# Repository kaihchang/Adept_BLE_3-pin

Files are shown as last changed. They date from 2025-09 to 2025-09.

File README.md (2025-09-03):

# Adept_BLE_3-pin

Took open source [Adept BLE design](https://github.com/taichan1113/AdeptBLE) and altered PCB &amp; casing for 3-pin micro switches.

Note that the casing is designed for **1.2mm thick PCBs.** Very important.

My version of ZMK firmware is [here.](https://github.com/kaihchang/zmk-config-adept)

Altered PCB:


Altered cases:
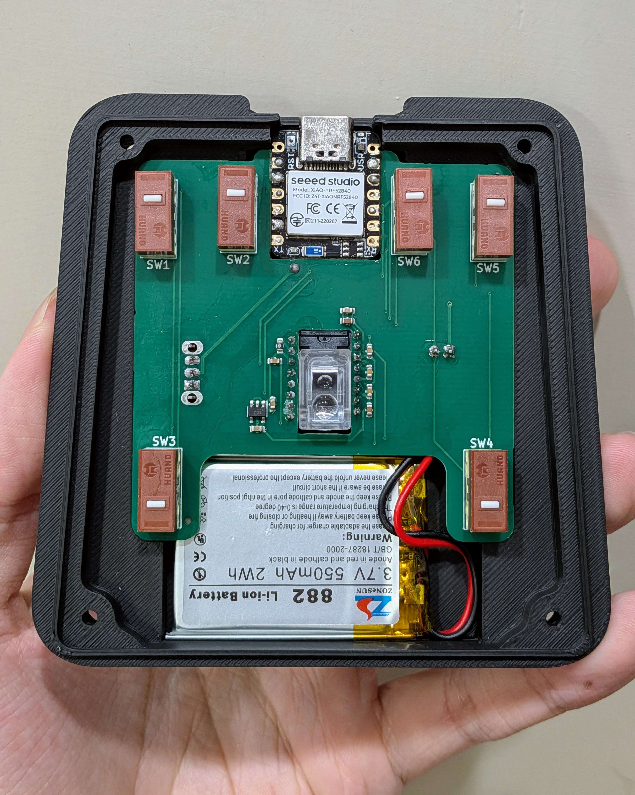
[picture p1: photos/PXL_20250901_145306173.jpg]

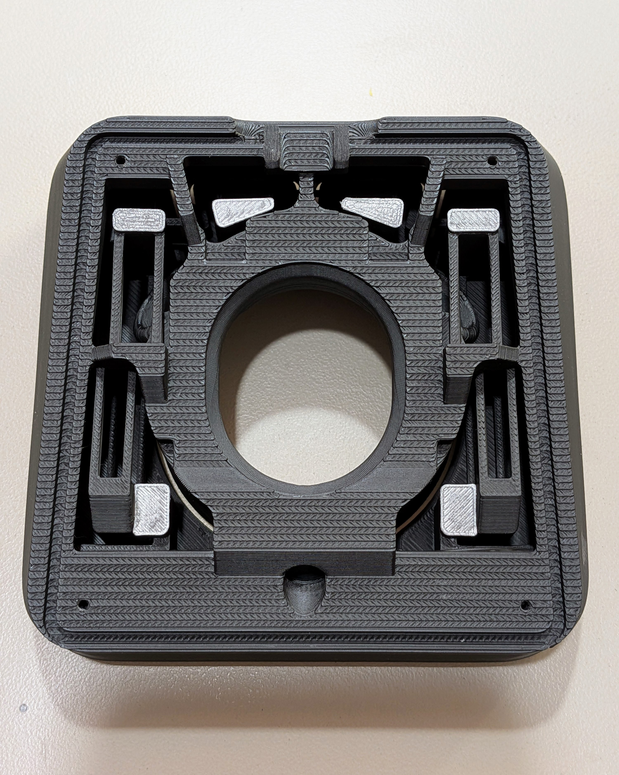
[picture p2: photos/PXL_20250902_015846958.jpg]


Finished build:
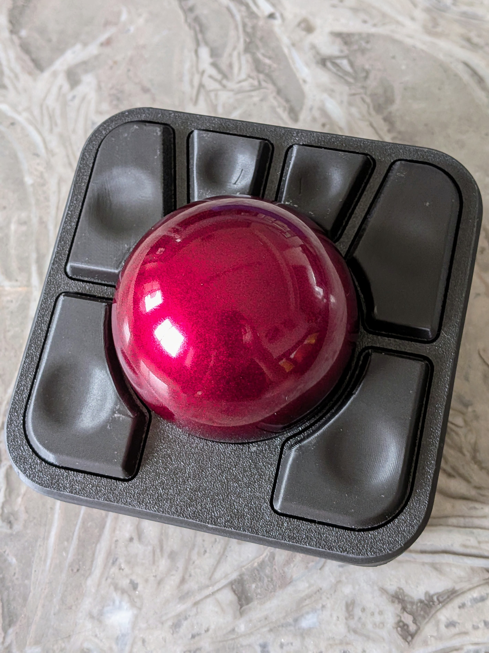
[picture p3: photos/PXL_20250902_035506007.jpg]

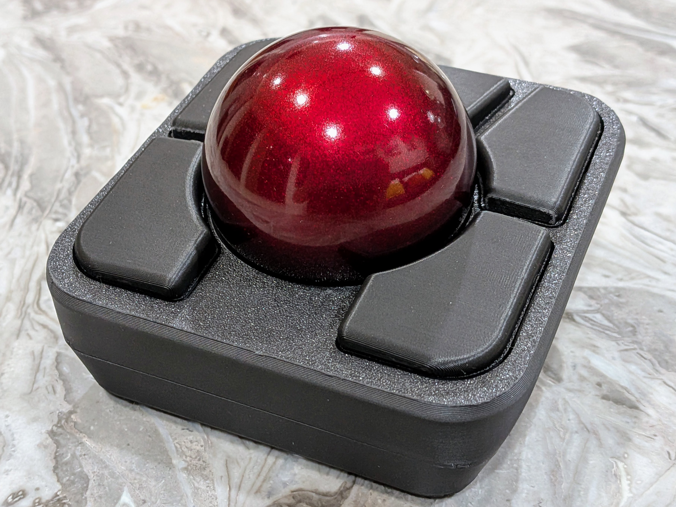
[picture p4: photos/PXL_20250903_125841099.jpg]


Supports BTU and magnet caps. BTW I used CY-8H BTUs and wasn't really satisfied with the quality, even after lubing with grease. SP-8 ones may be a better bet if *Rexroth R053XX8XX (7210)* isn't available or out of price range.
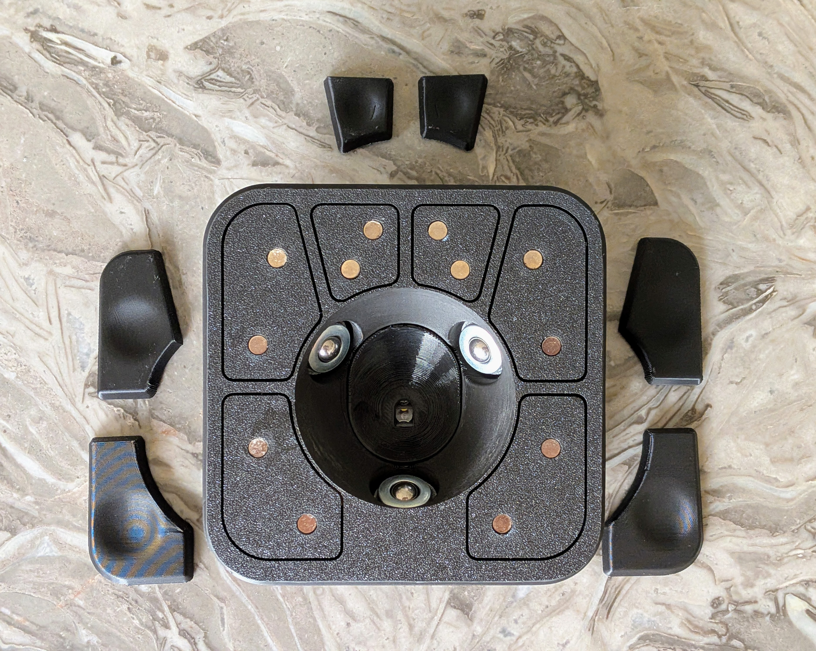
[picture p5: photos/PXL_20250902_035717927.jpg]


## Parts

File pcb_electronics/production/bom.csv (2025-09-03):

Designator | Footprint | Quantity | Value | LCSC Part #
C1 | 0603 | 1 | 10n | C19666
C2, C7 | 0603 | 2 | 100n | C19666
C3 | 0603 | 1 | 3.3u/16V | C19666
C4 | 0603 | 1 | 0.1u | C14663
C5 | 0603 | 1 | 1u | C15849
C6 | 0603 | 1 | 100n (X7R) | C19666
C8 | 0603 | 1 | 10u (X7R) | C19666
C9 | 0603 | 1 | 10n (X7R) | C19666
J1 | JST_XH_S2B-XH-A-1_1x02_P2.50mm_Horizontal | 1 | Conn_01x02
J2, J3 | PinHeader_1x06_P2.54mm_Vertical | 2 | Conn_01x06
J4 | PinHeader_1x01_P2.54mm_Vertical | 1 | Conn_01x01
PSW1 | SW_Slide_SPDT_Straight_CK_OS102011MS2Q | 1 | SW_SPDT
R1 | 0603 | 1 | 2M
SW1, SW2, SW3, SW4, SW5, SW6 | SW_D2FC-1F_3_OMR_edit | 6 | D2LS-21
U1 | SOT-23-5 | 1 | TCR2EF19 | C146366
U2 | PMW3610 | 1 | PMW3610

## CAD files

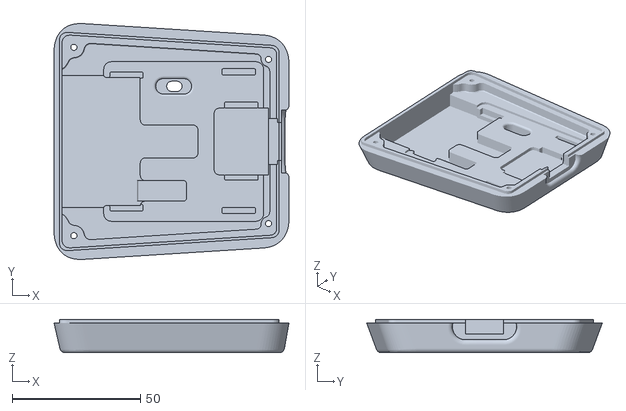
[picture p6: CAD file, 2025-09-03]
3d_print_casings/bottom_casing_xh254.stl
91.6 x 91.9 x 13.0

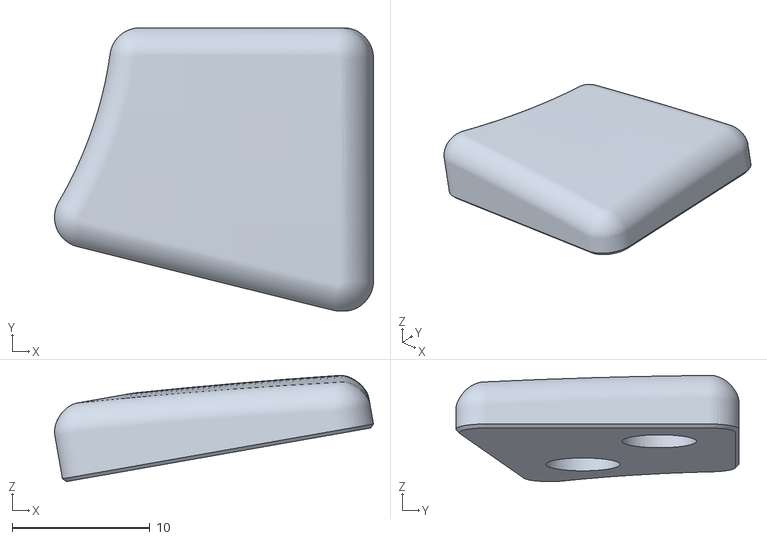
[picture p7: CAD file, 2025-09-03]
3d_print_casings/magnet_buttons/flat/button_flat_5x1.2mm_3.stl
23.1 x 20.6 x 7.71

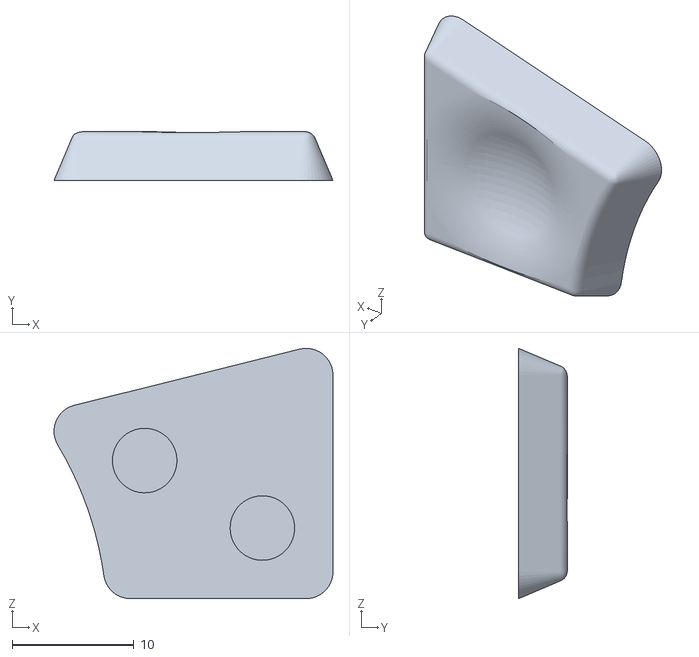
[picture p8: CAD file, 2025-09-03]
3d_print_casings/magnet_buttons/spherical/button_spherical_5x1.5mm_3.stl
22.9 x 4.00 x 20.6

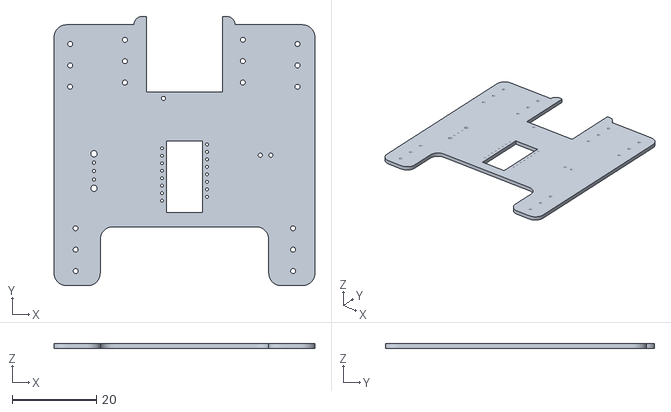
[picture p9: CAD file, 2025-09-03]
pcb_electronics/adept_3pin_pcb_edit.stl
62.0 x 64.0 x 1.20

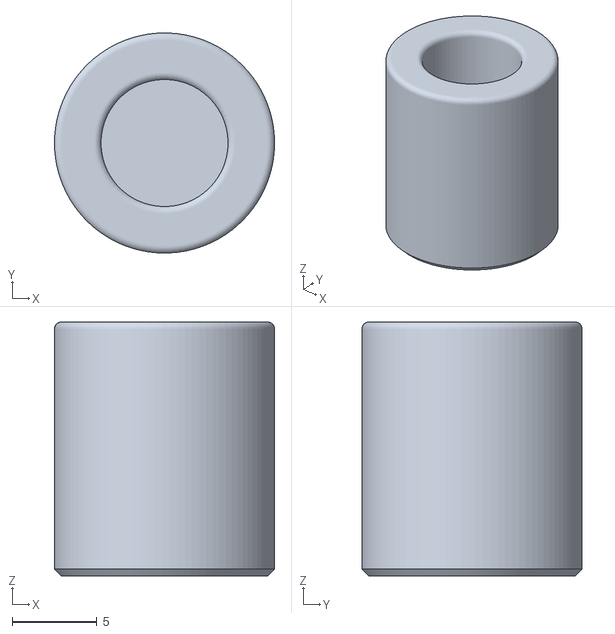
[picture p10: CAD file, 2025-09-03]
3d_print_casings/BTU_pusher.stl
13.0 x 13.0 x 15.0

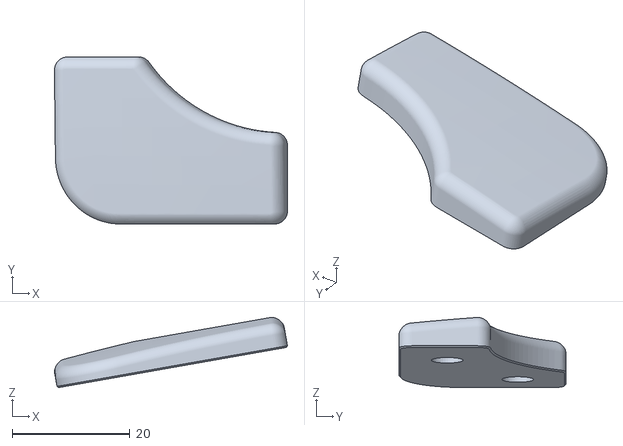
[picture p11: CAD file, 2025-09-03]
3d_print_casings/magnet_buttons/flat/button_flat_5x1.2mm_6.stl
39.6 x 28.4 x 11.9

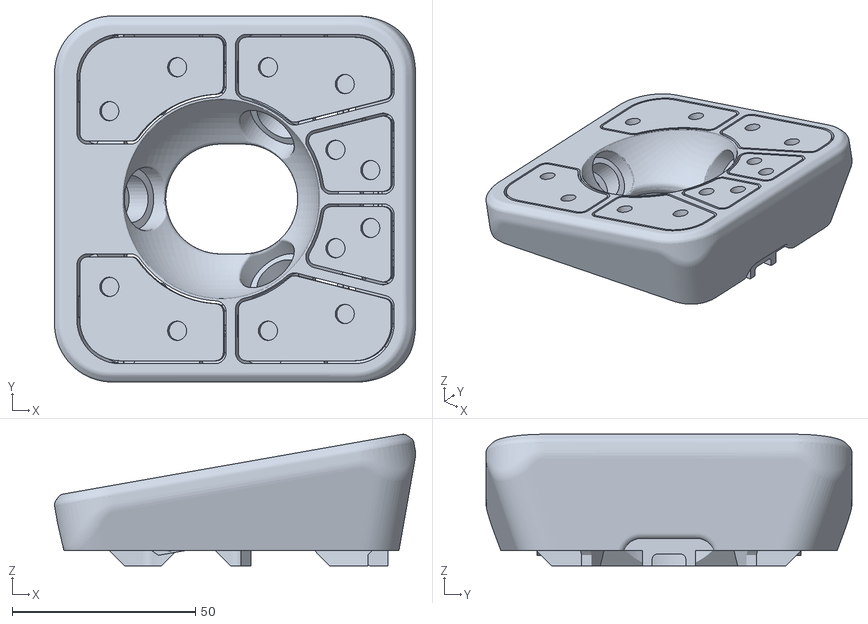
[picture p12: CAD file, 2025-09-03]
pcb_electronics/adept_55mm_top_casing_edit.stl
98.7 x 100.0 x 36.0

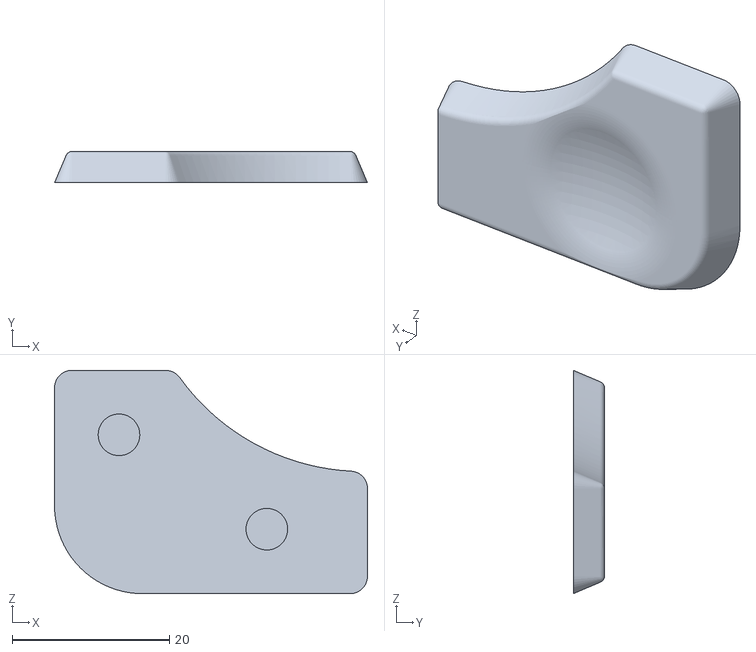
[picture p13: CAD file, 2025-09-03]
3d_print_casings/magnet_buttons/spherical/button_spherical_5x1.5mm_6.stl
39.8 x 4.00 x 28.4

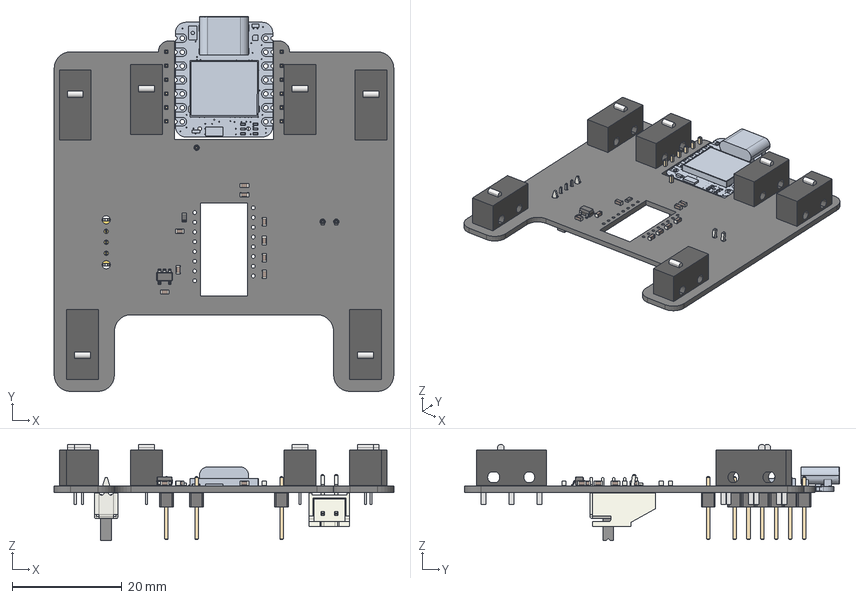
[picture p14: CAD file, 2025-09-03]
pcb_electronics/sensor.step
62.0 x 68.5 x 17.6 mm
SOT-23-5
C_0603_1608Metric x 9
sensor 1.8.1
D2F_01F_BASE x 6
D2F_01F_ACTUATOR x 6
R_0603_1608Metric
PinHeader_1x06_P2.54mm_Vertical x 2
SW_Slide_SPDT_Straight_CK_OS102011MS2Q
PinHeader_1x01_P2.54mm_Vertical
JST_XH_S2B-XH-A-1_1x02_P2.50mm_Horizontal
sensor_PCB

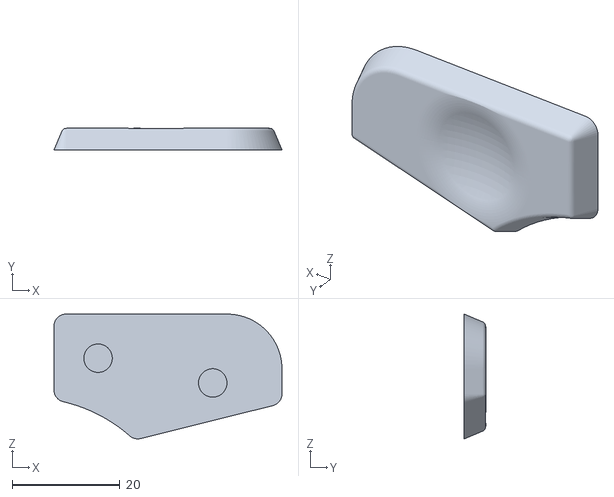
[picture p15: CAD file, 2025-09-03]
3d_print_casings/magnet_buttons/spherical/button_spherical_5x1.5mm_2.stl
42.4 x 4.00 x 23.2

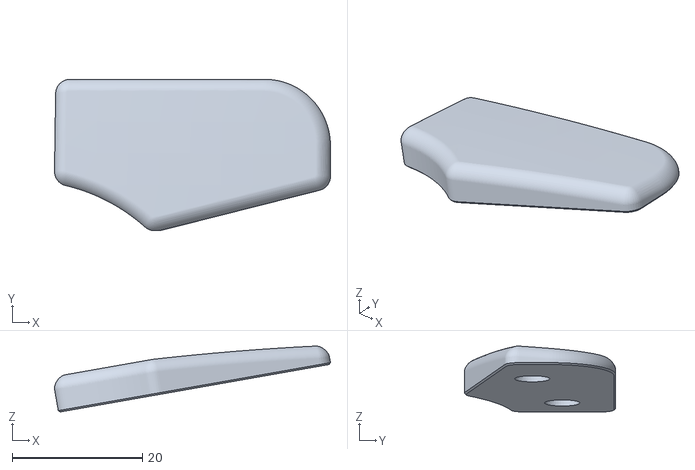
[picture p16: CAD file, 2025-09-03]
3d_print_casings/magnet_buttons/flat/button_flat_5x1.2mm_1.stl
42.3 x 23.2 x 10.1

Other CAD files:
3d_print_casings/magnet_buttons/spherical/button_spherical_5x1.5mm_4.stl
3d_print_casings/magnet_buttons/flat/button_flat_5x1.2mm_2.stl
3d_print_casings/top_casing_55mm.stl
3d_print_casings/magnet_buttons/flat/button_flat_5x1.2mm_5.stl
3d_print_casings/magnet_buttons/spherical/button_spherical_5x1.5mm_1.stl
3d_print_casings/magnet_buttons/flat/button_flat_5x1.2mm_4.stl

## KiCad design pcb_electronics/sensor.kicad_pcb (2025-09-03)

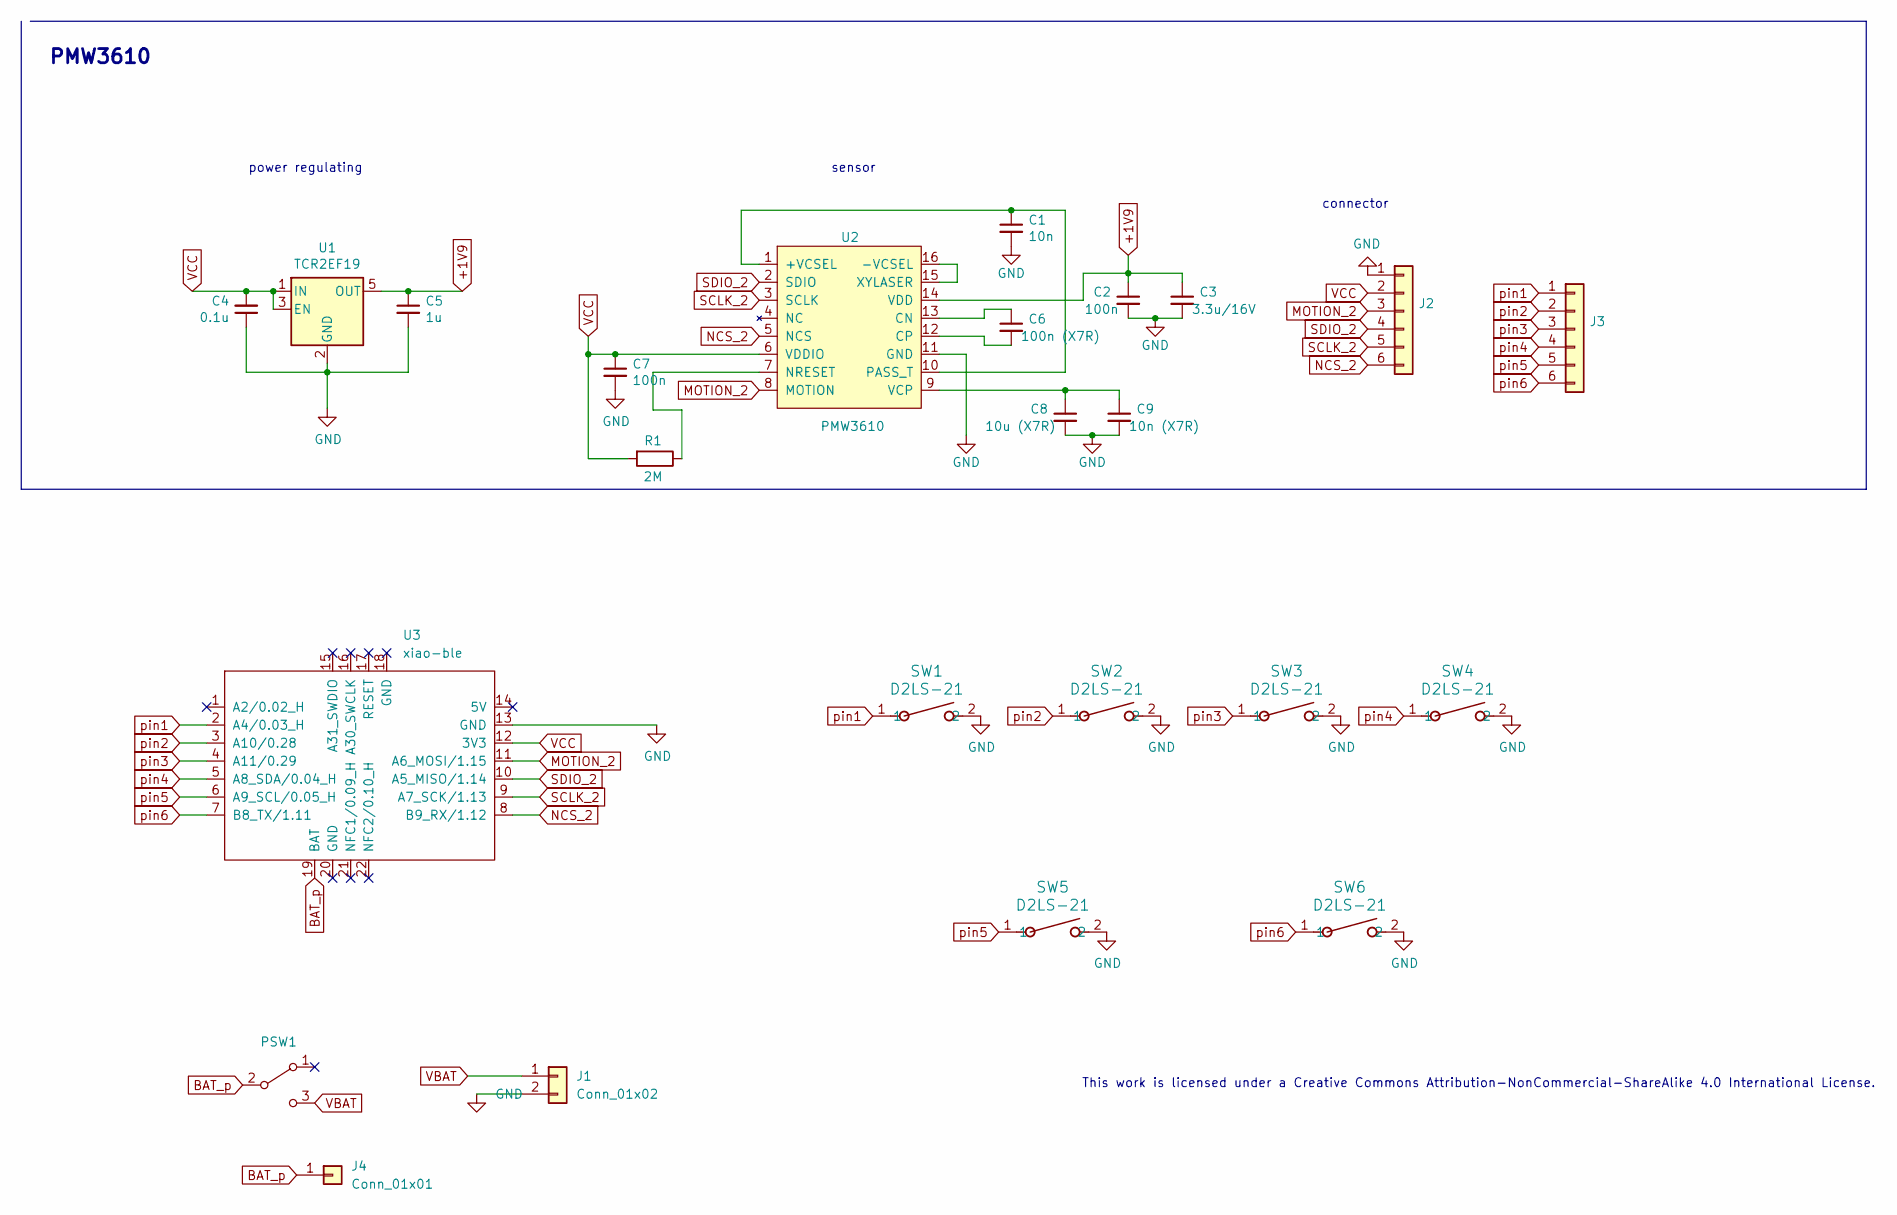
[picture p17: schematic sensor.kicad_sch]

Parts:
C1: 10n; C_0603_1608Metric; LCSC C19666
C2, C7: 100n; C_0603_1608Metric; LCSC C19666
C3: 3.3u/16V; C_0603_1608Metric; LCSC C19666
C4: 0.1u; C_0603_1608Metric; LCSC C14663
C5: 1u; C_0603_1608Metric; LCSC C15849
C6: 100n (X7R); C_0603_1608Metric; LCSC C19666
C8: 10u (X7R); C_0603_1608Metric; LCSC C19666
C9: 10n (X7R); C_0603_1608Metric; LCSC C19666
J1: Conn_01x02; JST_XH_S2B-XH-A-1_1x02_P2.50mm_Horizontal
J2, J3: Conn_01x06; PinHeader_1x06_P2.54mm_Vertical
J4: Conn_01x01; PinHeader_1x01_P2.54mm_Vertical
PSW1: SW_SPDT; SW_Slide_SPDT_Straight_CK_OS102011MS2Q
R1: 2M; R_0603_1608Metric
SW1, SW2, SW3, SW4, SW5, SW6: D2LS-21; SW_D2FC-1F_3_OMR_edit
U1: TCR2EF19; SOT-23-5; LCSC C146366
U2: PMW3610
U3: xiao-ble; xiao-ble-tht

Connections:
+1V9: C2.1, C3.1, C5.1, U1.5 (OUT), U2.14 (VDD)
BAT_p: J4.1, PSW1.2 (B), U3.19 (BAT)
GND: C1.2, C2.2, C3.2, C4.1, C5.2, C7.2, C8.2, C9.2, J1.2, J2.1, SW1.2, SW2.2, SW3.2, SW4.2, SW5.2, SW6.2, U1.2 (GND), U2.11 (GND), U3.13 (GND)
MOTION_2: J2.3, U2.8 (MOTION), U3.11 (A6_MOSI/1.15)
NCS_2: J2.6, U2.5 (NCS), U3.8 (B9_RX/1.12)
unnamed: C1.1, U2.1 (+VCSEL), U2.10 (PASS_T)
unnamed: U2.15 (XYLASER), U2.16 (-VCSEL)
unnamed: C6.1, U2.13 (CN)
unnamed: C6.2, U2.12 (CP)
unnamed: R1.1, U2.7 (NRESET)
unnamed: C8.1, C9.1, U2.9 (VCP)
SCLK_2: J2.5, U2.3 (SCLK), U3.9 (A7_SCK/1.13)
SDIO_2: J2.4, U2.2 (SDIO), U3.10 (A5_MISO/1.14)
VBAT: J1.1, PSW1.3 (C)
VCC: C4.2, C7.1, J2.2, R1.2, U1.1 (IN), U1.3 (EN), U2.6 (VDDIO), U3.12 (3V3)
pin1: J3.1, SW1.1, U3.2 (A4/0.03_H)
pin2: J3.2, SW2.1, U3.3 (A10/0.28)
pin3: J3.3, SW3.1, U3.4 (A11/0.29)
pin4: J3.4, SW4.1, U3.5 (A8_SDA/0.04_H)
pin5: J3.5, SW5.1, U3.6 (A9_SCL/0.05_H)
pin6: J3.6, SW6.1, U3.7 (B8_TX/1.11)

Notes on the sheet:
This work is licensed under a Creative Commons Attribution-NonCommercial-ShareAlike 4.0 International License.
sensor
PMW3610
power regulating
connector

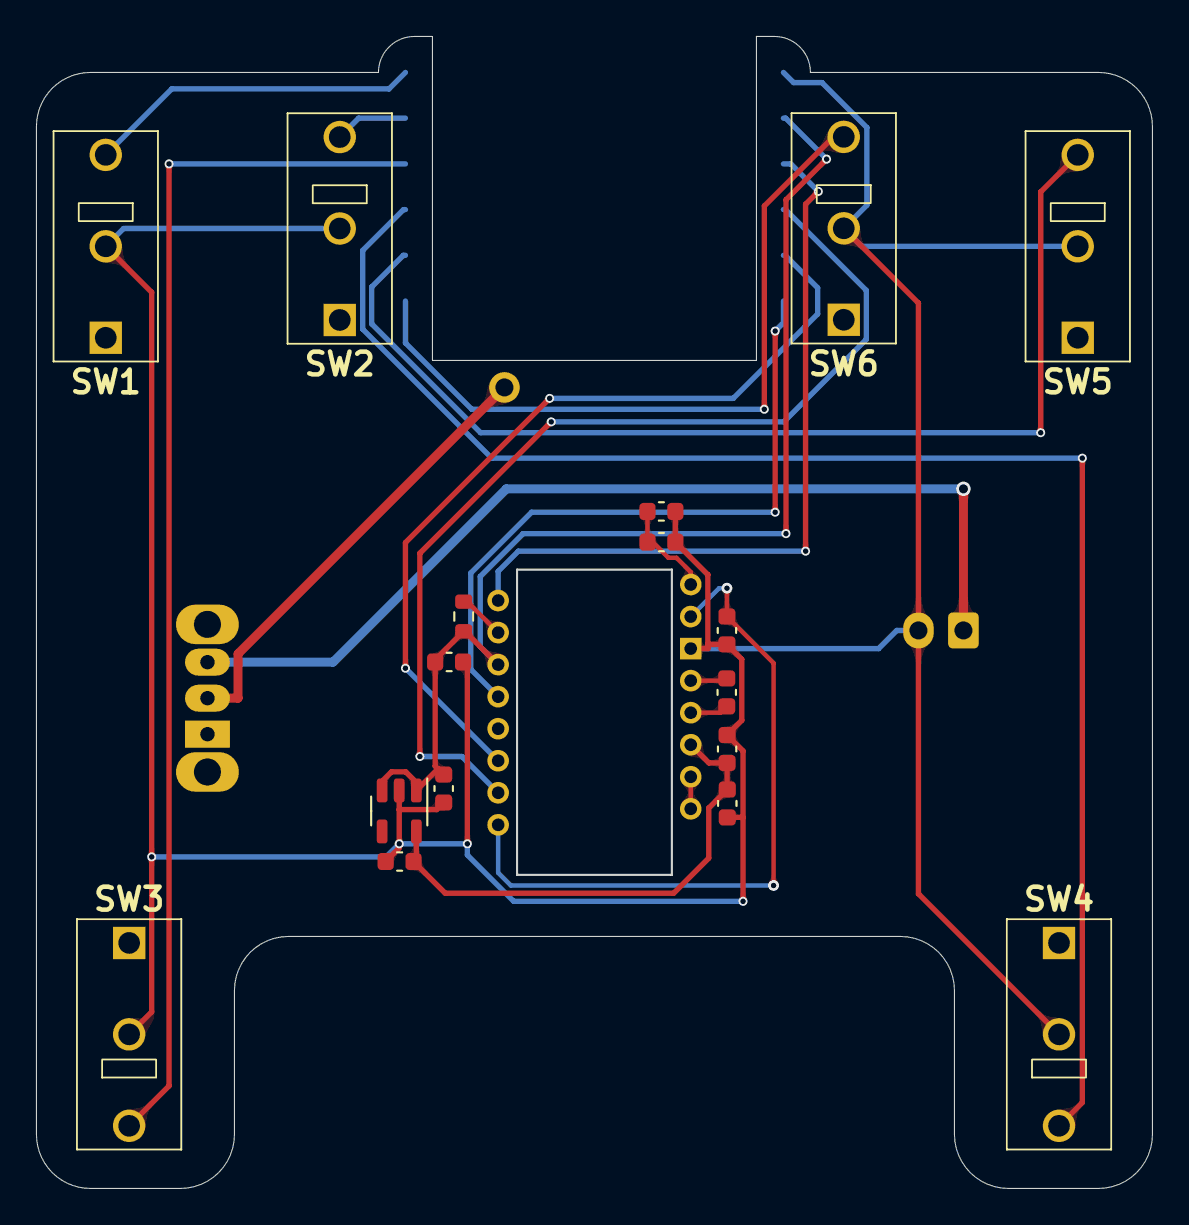
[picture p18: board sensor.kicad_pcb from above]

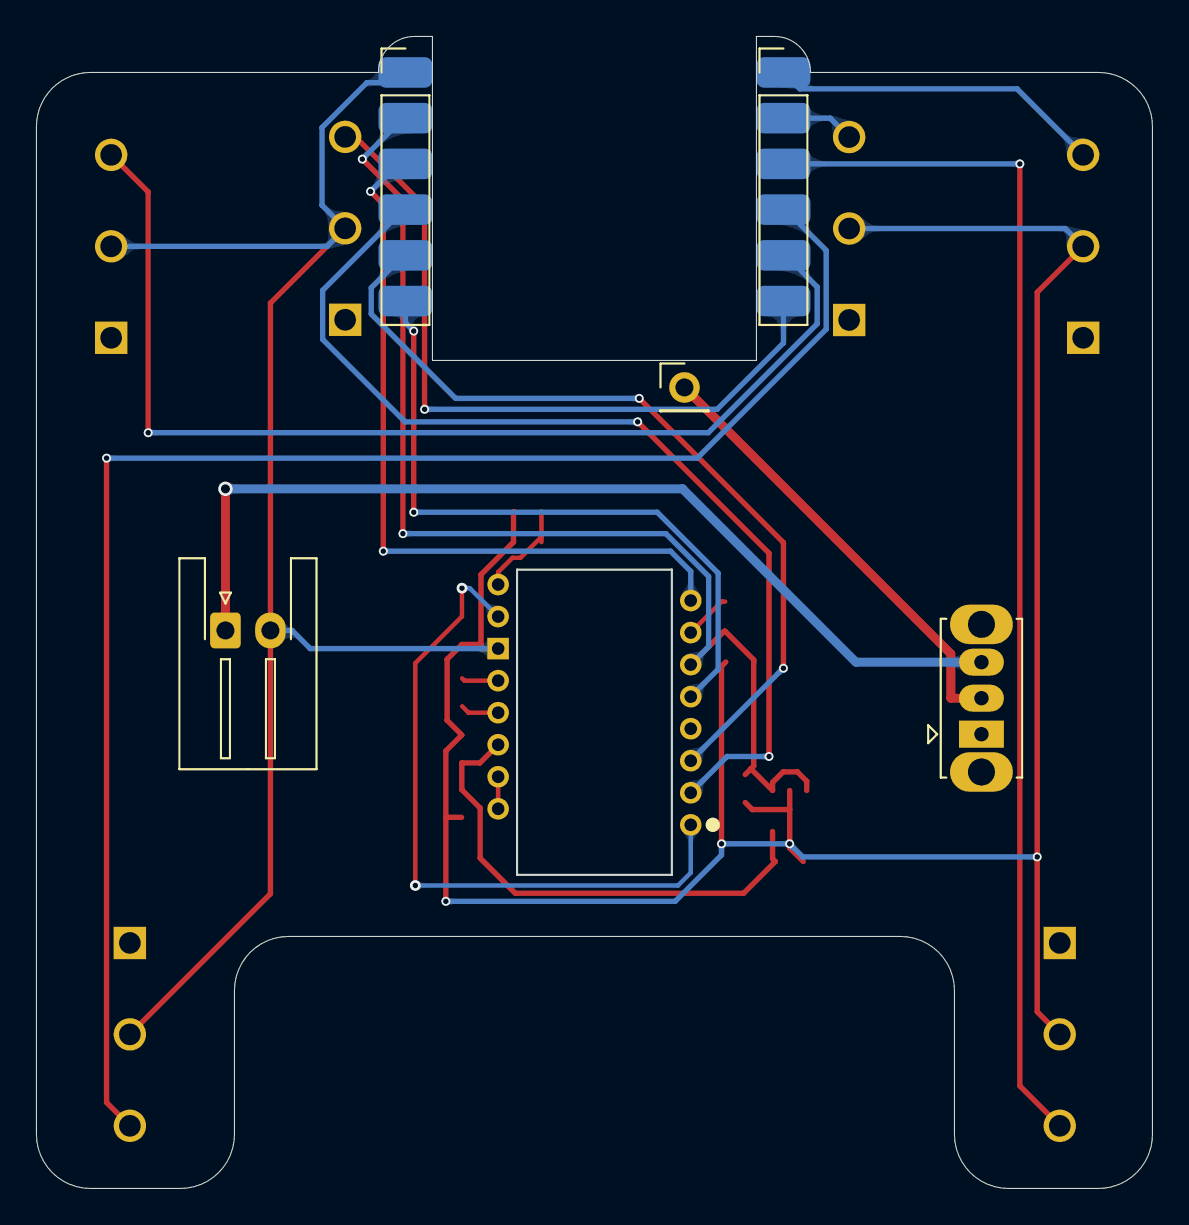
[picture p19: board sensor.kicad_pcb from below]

Board: 2 copper layers, 62.0 x 64.0 mm, 23 parts (6 on the bottom side), 21 nets.

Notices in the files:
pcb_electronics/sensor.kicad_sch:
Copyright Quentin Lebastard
